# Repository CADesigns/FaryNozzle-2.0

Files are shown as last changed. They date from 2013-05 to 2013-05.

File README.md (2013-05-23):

FaryNozzle-2.0
==============

Documentation of hot end FaryNozzle, based on FaryNozzle. (https://github.com/CADesigns/FaryNozzle-1.0)

Este trabajo está bajo una Licencia Creative Commons Atribución-CompartirIgual 3.0 Unported.
Reconocimiento - CompartirIgual (by-sa): Se permite el uso comercial de la obra y de las posibles obras 
derivadas, la distribución de las cuales se debe hacer con una licencia igual a la que regula la obra original.
http://creativecommons.org/licenses/by-sa/3.0/legalcode

farynozzle.com - info@farynozzle.com

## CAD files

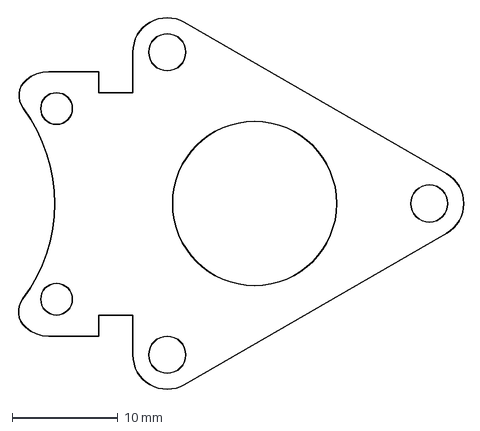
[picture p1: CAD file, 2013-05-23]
6 - Placa inferior.dxf
42.3 x 35.4 mm

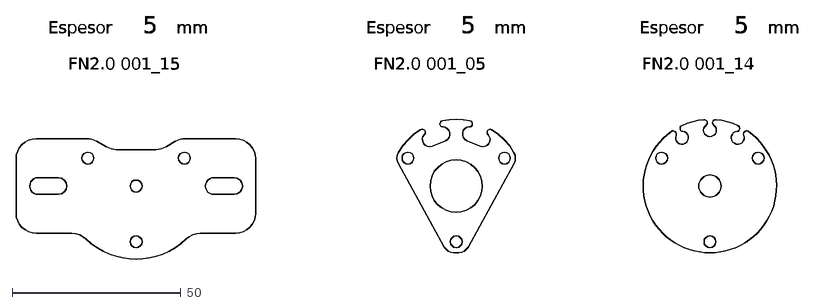
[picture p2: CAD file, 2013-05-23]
Cortes laser madera.dxf
Espesor
5
mm
FN2.0 001_15
FN2.0 001_05
FN2.0 001_14

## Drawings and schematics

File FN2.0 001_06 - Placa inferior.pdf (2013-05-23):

| A | B | C | D | E | F
1 | | | | | | | 1

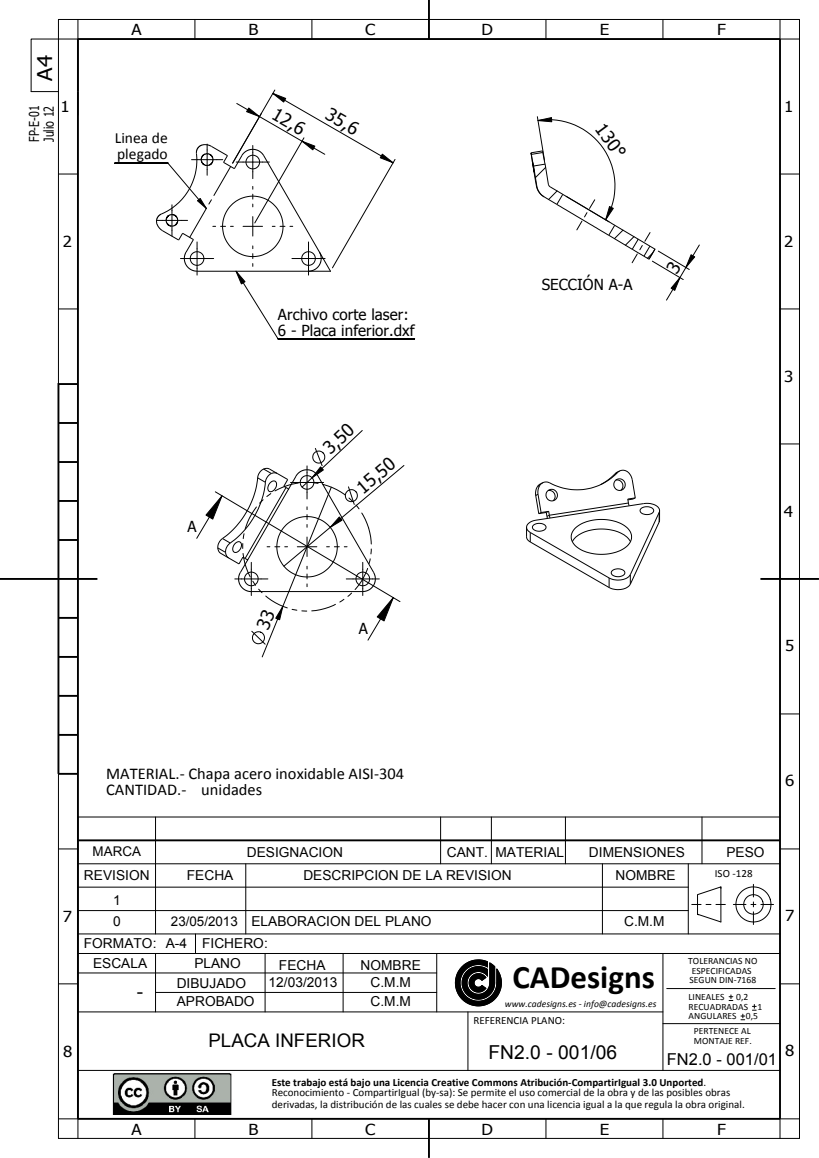
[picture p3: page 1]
CADesigns; Julio 12 A4; PLACA INFERIOR; MONTAJE REF.; PERTENECE AL; SECCIÓN A-A; Linea de plegado

Archivo corte laser:
6 - Placa inferior.dxf

MATERIAL.‐ Chapa acero inoxidable AISI‐304
CANTIDAD.‐ unidades

MARCA | DESIGNACION | CANT. | MATERIAL | DIMENSIONES | PESO
REVISION | FECHA | DESCRIPCION DE LA REVISION | NOMBRE | ISO ‐128
0 | 23/05/2013 | ELABORACION DEL PLANO | C.M.M
FORMATO: A-4 | FICHERO:
- | DIBUJADO | 12/03/2013 | C.M.M
APROBADO | | C.M.M

ESCALA | PLANO | FECHA | NOMBRE | www.cadesigns.es ‐ info@cadesigns.es | TOLERANCIAS NO ESPECIFICADAS SEGUN DIN‐7168 LINEALES 0,2 RECUADRADAS 1

ANGULARES 0,5 REFERENCIA PLANO:

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

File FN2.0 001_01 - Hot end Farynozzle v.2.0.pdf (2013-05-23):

54,5

0

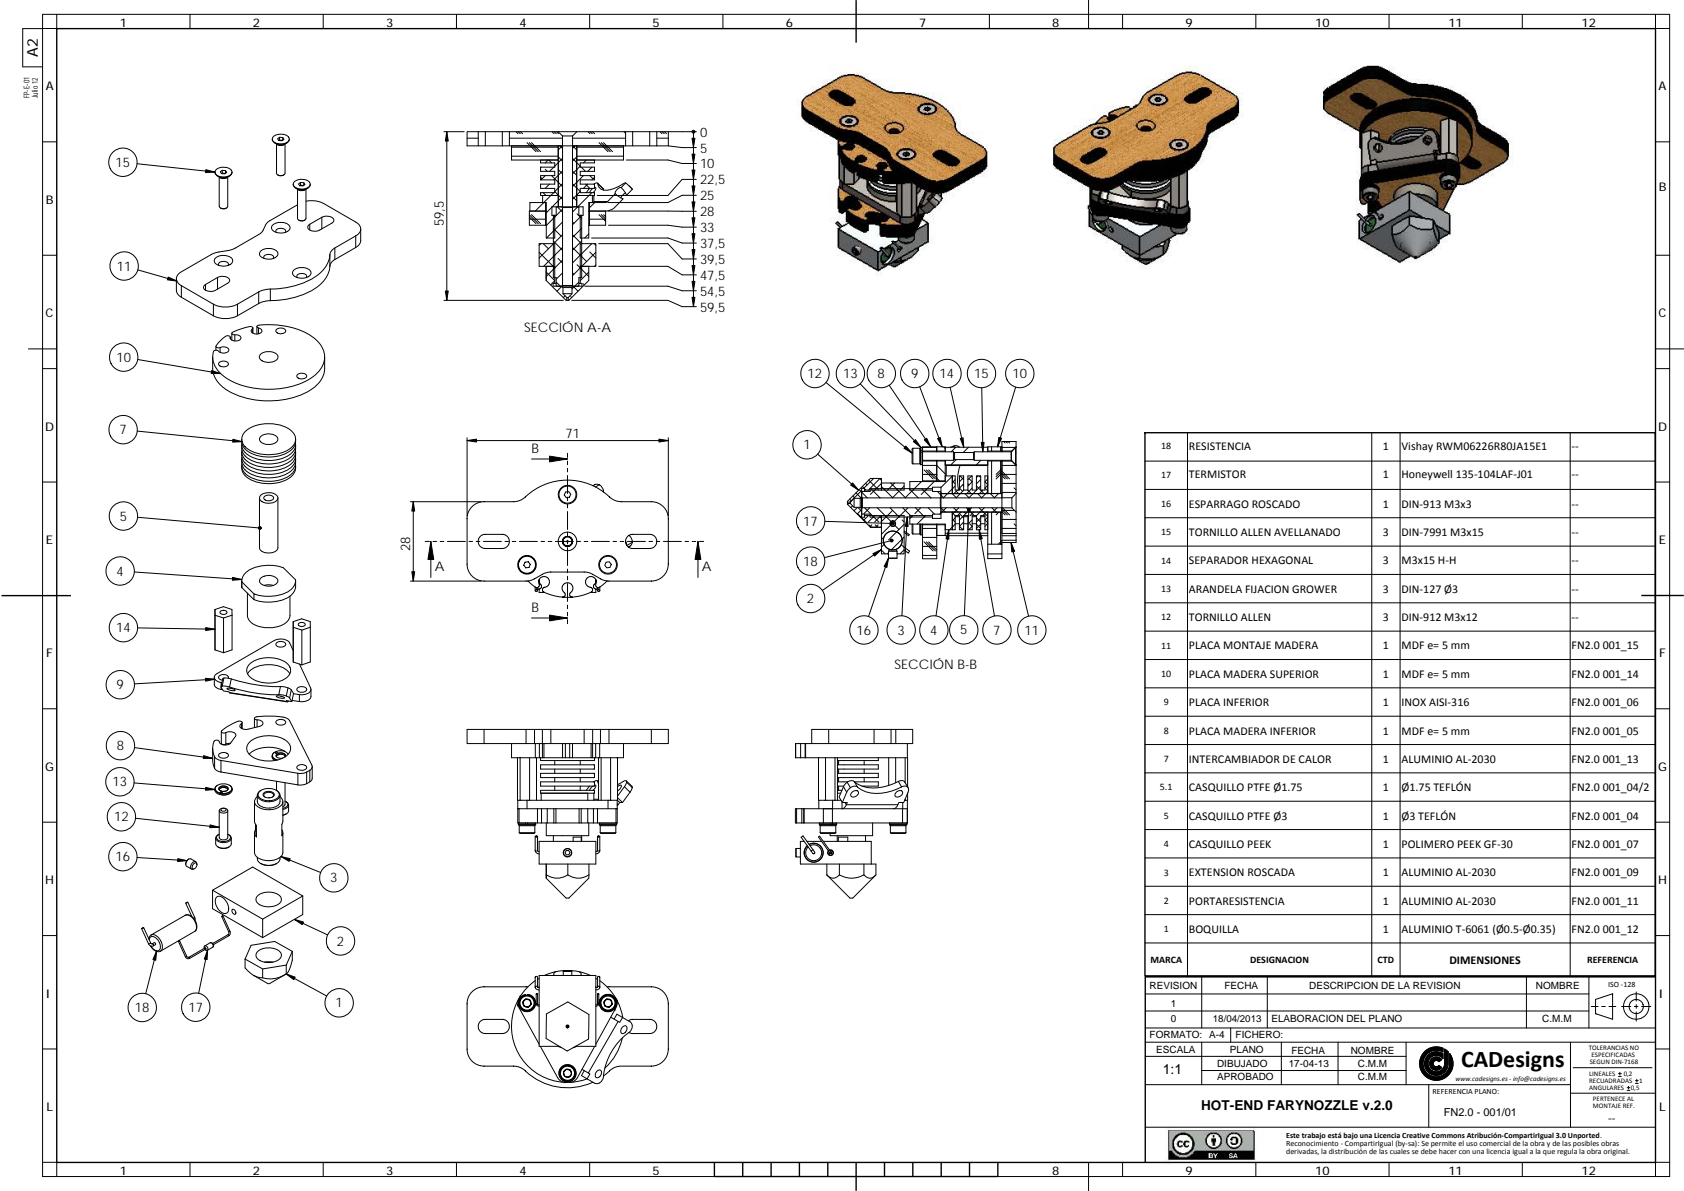
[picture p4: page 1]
Julio 12 A2; CADesigns; FORMATO: A-4; FICHERO:; HOT-END FARYNOZZLE v.2.0; MONTAJE REF.; REFERENCIA PLANO: FN2.0 - 001/01; PERTENECE AL; MARCA; DESIGNACION; CTD; DIMENSIONES; REFERENCIA; RESISTENCIA; Vishay RWM06226R80JA15E1; TERMISTOR; Honeywell 135‐104LAF‐J01; ESPARRAGO ROSCADO; DIN‐913 M3x3; TORNILLO ALLEN AVELLANADO; DIN‐7991 M3x15; SEPARADOR HEXAGONAL; ARANDELA FIJACION GROWER; DIN‐127 Ø3; TORNILLO ALLEN; DIN‐912 M3x12; PLACA MONTAJE MADERA; MDF e= 5 mm; PLACA MADERA SUPERIOR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

REVISION | FECHA | DESCRIPCION DE LA REVISION | NOMBRE | ISO ‐128
0 | 18/04/2013 | ELABORACION DEL PLANO | C.M.M

ESCALA | PLANO | FECHA | NOMBRE | www.cadesigns.es ‐ info@cadesigns.es | TOLERANCIAS NO ESPECIFICADAS SEGUN DIN‐7168 LINEALES 0,2 RECUADRADAS 1 ANGULARES 0,5
1:1 | DIBUJADO | 17-04-13 | C.M.M

APROBADO | | C.M.M

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

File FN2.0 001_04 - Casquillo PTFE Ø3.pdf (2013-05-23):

3,5

| A | B | C | D | E | F

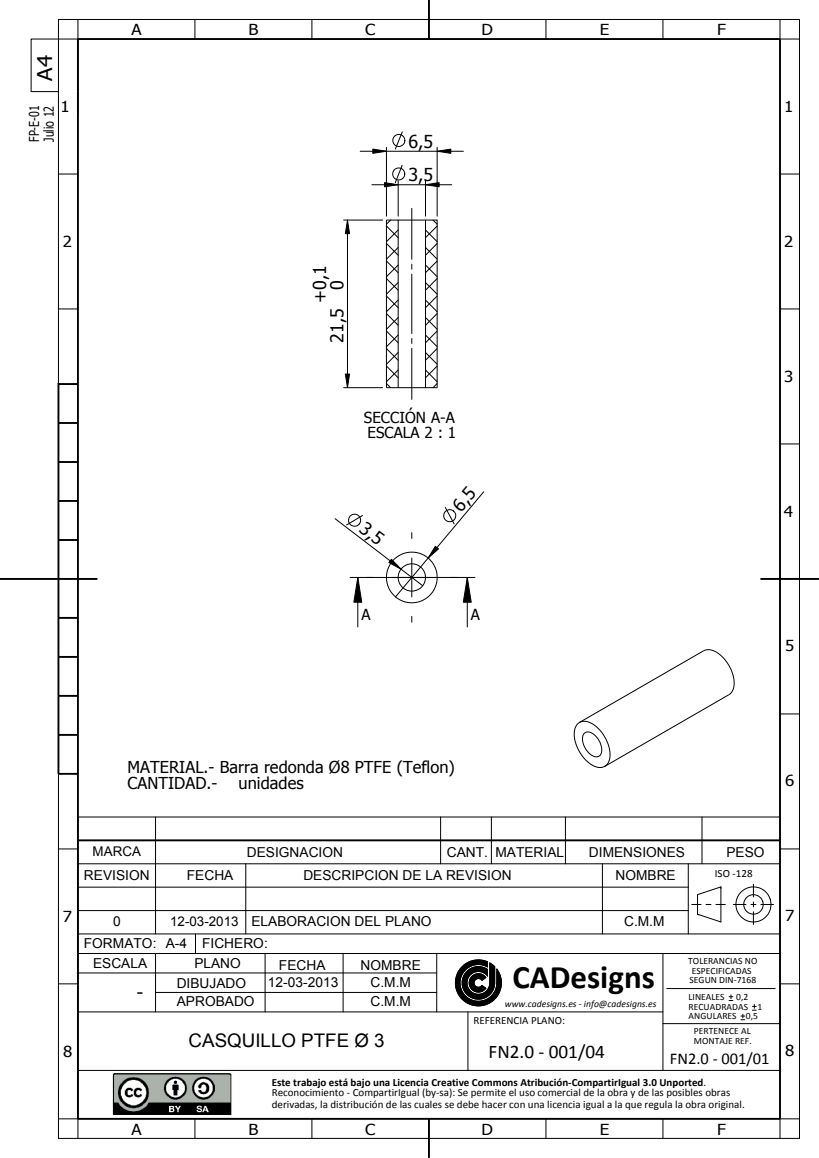
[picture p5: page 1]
SECCIÓN A-A ESCALA 2 : 1; CADesigns; Julio 12 A4; CASQUILLO PTFE Ø 3; MONTAJE REF.; REFERENCIA PLANO: FN2.0 ‐ 001/04; PERTENECE AL

MATERIAL.- Barra redonda Ø8 PTFE (Teflon)
CANTIDAD.- unidades

MARCA | DESIGNACION | CANT. | MATERIAL | DIMENSIONES | PESO
REVISION | FECHA | DESCRIPCION DE LA REVISION | NOMBRE | ISO ‐128

0 | 12-03-2013 | ELABORACION DEL PLANO | C.M.M
FORMATO: A-4 | FICHERO:
ESCALA | PLANO | FECHA | NOMBRE | www.cadesigns.es ‐ info@cadesigns.es | TOLERANCIAS NO ESPECIFICADAS SEGUN DIN‐7168 LINEALES 0,2 RECUADRADAS 1 ANGULARES 0,5
- | DIBUJADO | 12-03-2013 | C.M.M
APROBADO | | C.M.M

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

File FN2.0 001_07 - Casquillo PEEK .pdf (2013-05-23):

EC= 17

A

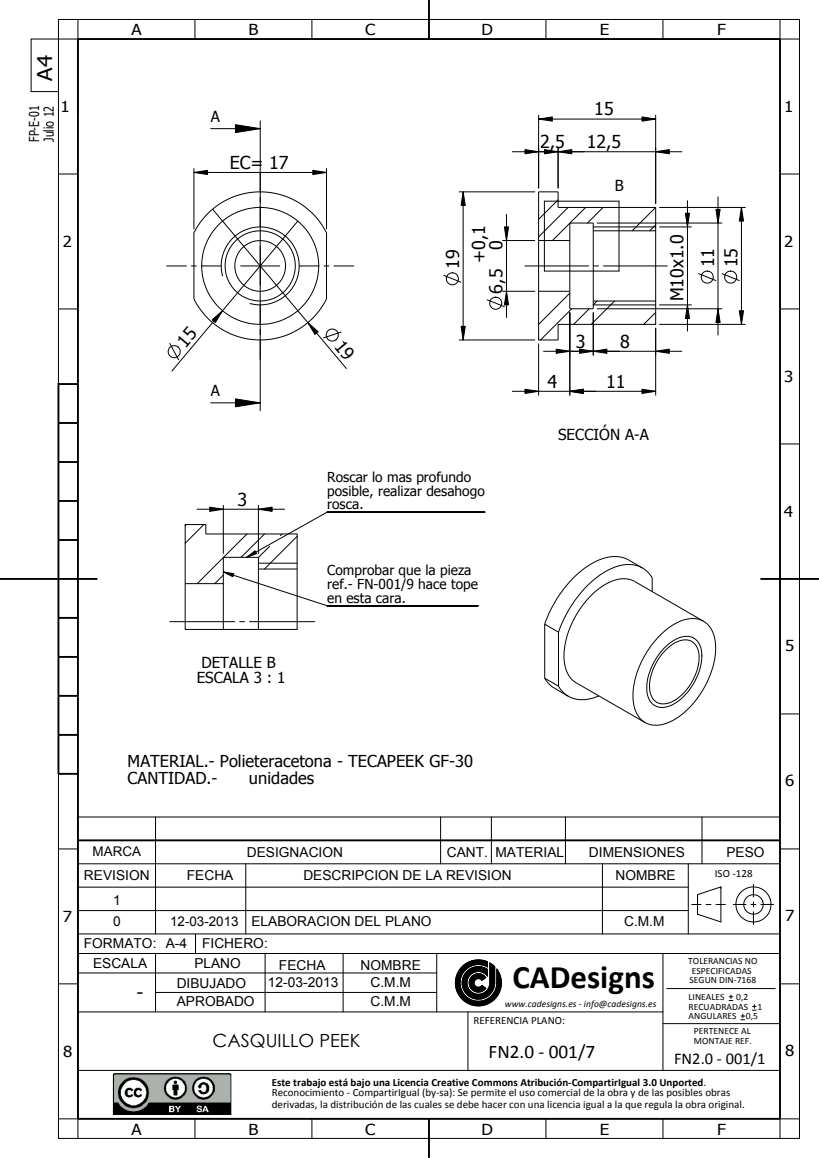
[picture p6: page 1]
SECCIÓN A-A; ESCALA 3 : 1; DETALLE B; CANTIDAD.-; unidades; CADesigns; Julio 12 A4; CASQUILLO PEEK; MONTAJE REF.; PERTENECE AL

Roscar lo mas profundo
posible, realizar desahogo
rosca.

Comprobar que la pieza
ref.- FN-001/9 hace tope
en esta cara.

MATERIAL.- Polieteracetona - TECAPEEK GF-30

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

ANGULARES 0,5 REFERENCIA PLANO:

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

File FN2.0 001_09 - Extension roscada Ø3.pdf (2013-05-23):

| A | B | C | D | E | F
1 | M10x1 | | | | | | 1

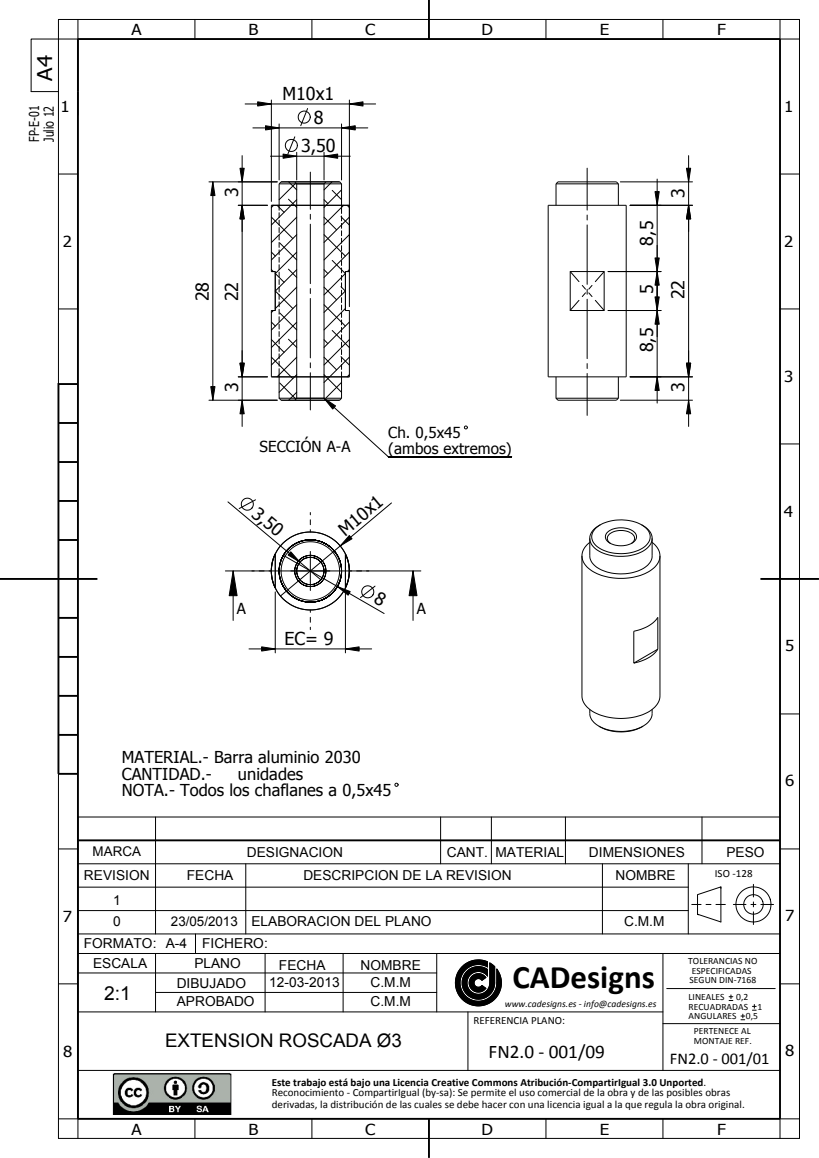
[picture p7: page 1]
CANTIDAD.-; unidades; CADesigns; Julio 12 A4; EXTENSION ROSCADA Ø3; MONTAJE REF.; PERTENECE AL; SECCIÓN A-A; (ambos extremos)

MATERIAL.- Barra aluminio 2030
NOTA.- Todos los chaflanes a 0,5x45

MARCA | DESIGNACION | CANT. | MATERIAL | DIMENSIONES | PESO
REVISION | FECHA | DESCRIPCION DE LA REVISION | NOMBRE | ISO ‐128
0 | 23/05/2013 | ELABORACION DEL PLANO | C.M.M
FORMATO: A-4 | FICHERO:
2:1 | DIBUJADO | 12-03-2013 | C.M.M

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

APROBADO | | C.M.M

ANGULARES 0,5 REFERENCIA PLANO:

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

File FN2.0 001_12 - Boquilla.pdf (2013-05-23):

A | B | C | D | E | F
1 | 1 11 | 1

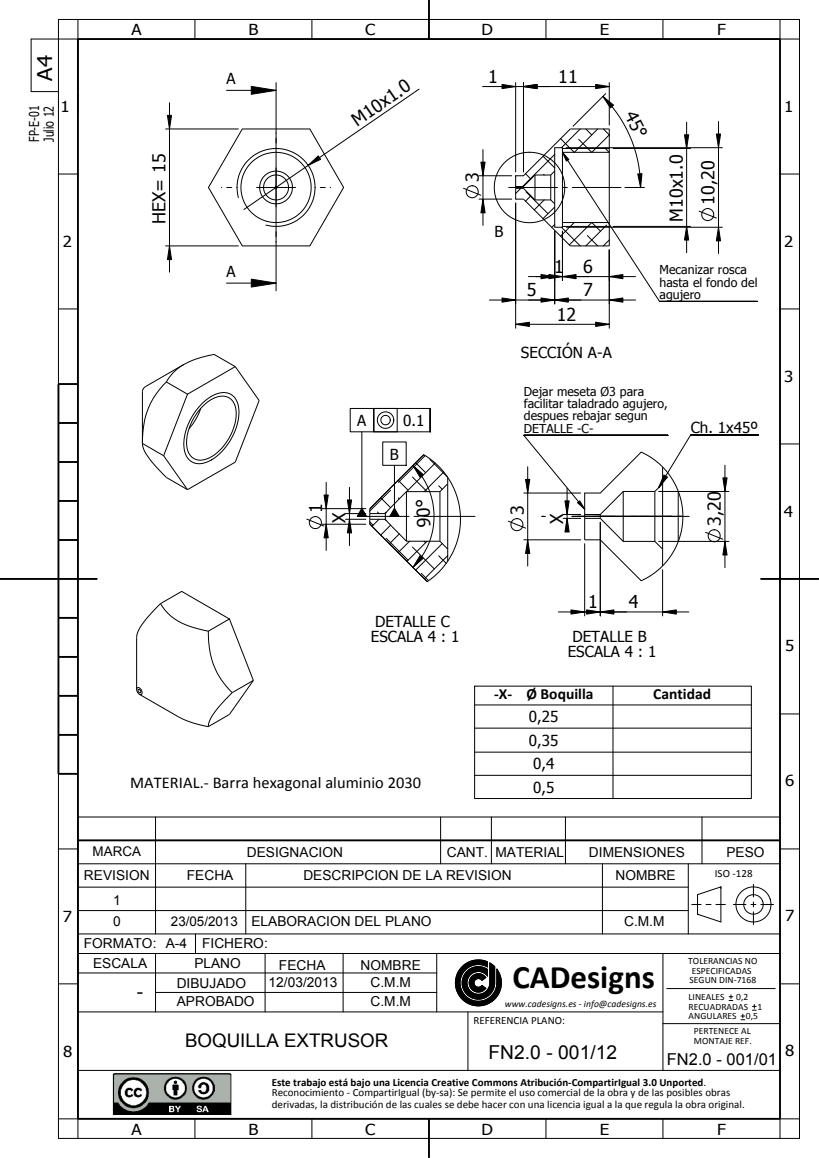
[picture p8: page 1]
ESCALA 4 : 1; DETALLE C; CADesigns; Julio 12 A4; BOQUILLA EXTRUSOR; MONTAJE REF.; PERTENECE AL; ‐X‐ Ø Boquilla; Cantidad; HEX= 15; SECCIÓN A-A; DETALLE B

Mecanizar rosca
hasta el fondo del
agujero

Dejar meseta Ø3 para
facilitar taladrado agujero,
despues rebajar segun
DETALLE -C- X

MATERIAL.‐ Barra hexagonal aluminio 2030

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

ANGULARES 0,5 REFERENCIA PLANO:

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
